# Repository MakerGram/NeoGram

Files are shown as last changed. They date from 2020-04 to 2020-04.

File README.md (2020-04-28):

# NeoGram v0.0.1α 🎨
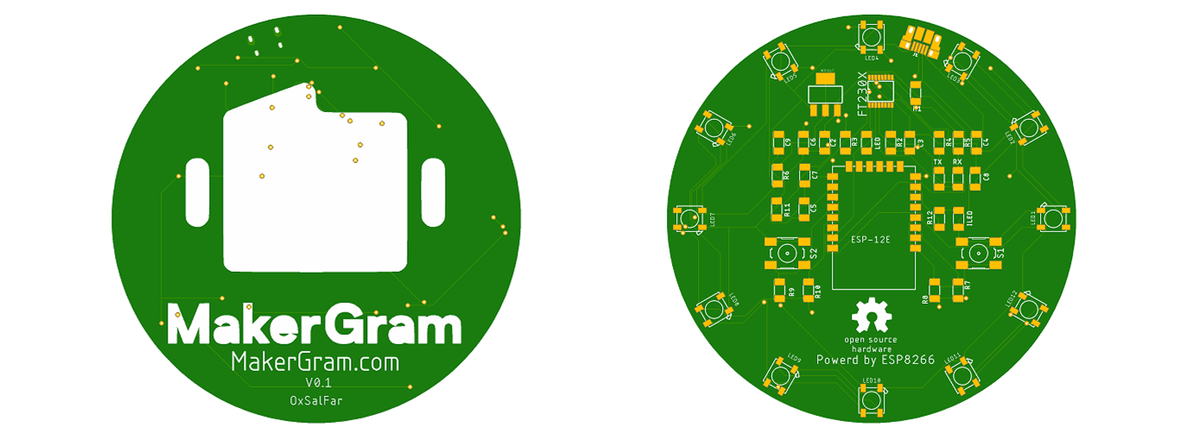
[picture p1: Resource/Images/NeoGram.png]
NeoGram


NeoGram is an ESP8266 based Open Source Hardware  Development board aimed to provide experiments on NeoPixels (WS2812B) using ESP8266. 

NeoGram is Powerd by [ESP8266-12E Module](Documents/ESP12E-Datasheet.pdf) which is encapsulates <b>Tensilica L106</b> integrates industry-leading ultra low power 32-bit MCU micro, with the 16-bit short mode,
Clock speed support 80 MHz, 160 MHz, supports the RTOS, integrated Wi-Fi MAC/BB/RF/PA/LNA, on-board antenna. The 12 of the  <b>WS2812B</b> can be progarmme indvidualy as maker wish to make there project colorfull 🌈.  

###  Features 

* 12 x Programmble WS2812B
* Plug and Play
* Inbuilt WiFi
* Inbuilt USB to UART
* Inbuild Voltage Regulator
* Reset button
* Power led
* MicroUSB port for programming and debugging 
* USB port can act like serial port, keyboard, mouse, joystick or MIDI!
* Powerd by ESP8266-12E - 32 bit, running 3.3v at 160 MHz
* Arduino Comptable 
* Micropython Compatble
* OpenSource Hardware ❤️

<br>

<hr>

## Schematic 

<p align="center">
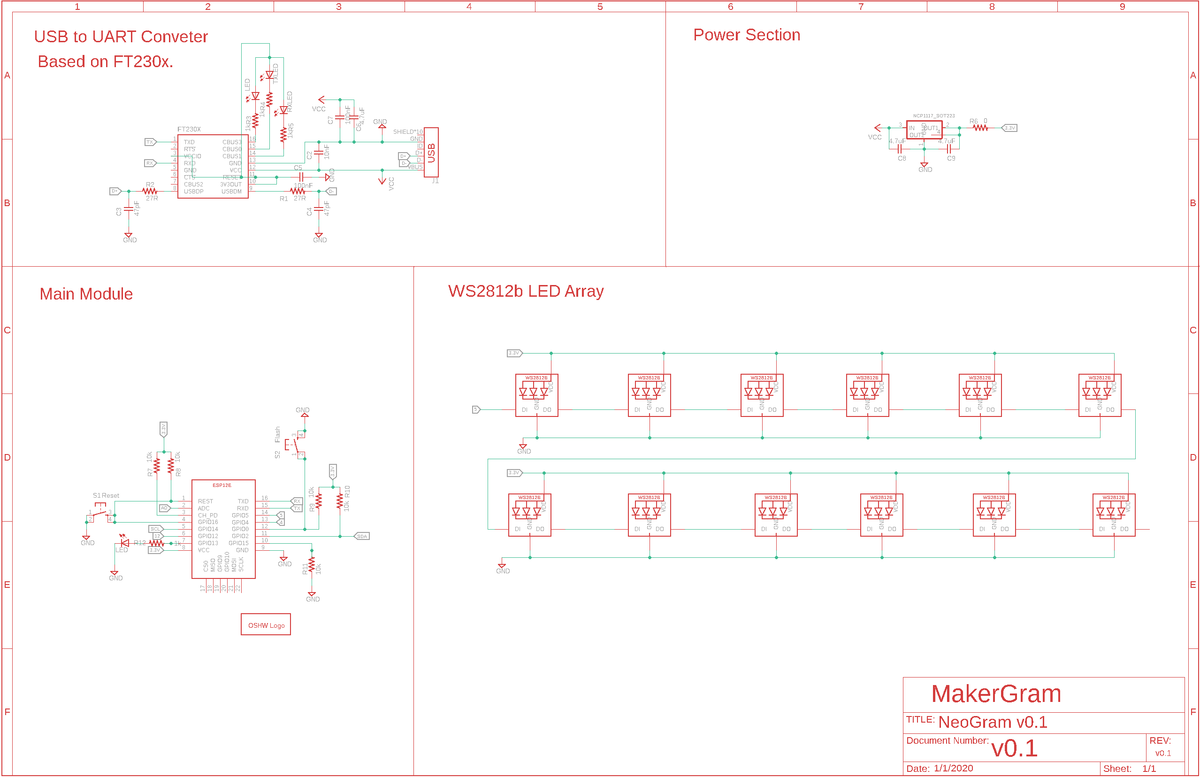
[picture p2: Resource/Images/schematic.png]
  
</p>

The [NeoGram Schematic](Hardware) Divided into Four Sections.

* ESP8266 Main Module
* WS2812B LED Array
* USB to UART
* Power Section

<hr>

## ESP8266

<p align="center">
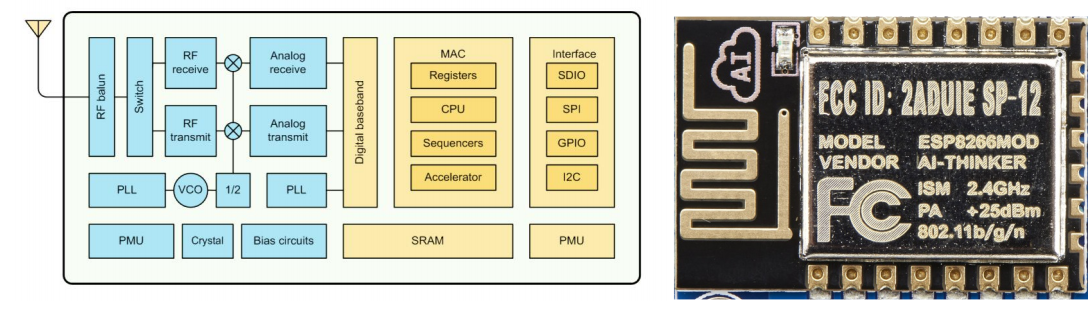
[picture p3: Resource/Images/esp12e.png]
  
</p>

The ESP8266 processor from Espressif is an 80 MHz microcontroller with a full WiFi front-end (both as client and access point) and TCP/IP stack with DNS support as well. While this chip has been very popular, its also been very difficult to use. Most of the low cost modules are not breadboard friendly, don't have an onboard 1000mA 3.3V regulator or level shifting.

The NeoGram comes with a onboard 1000mA 3.3v regulator with Arduino/MicroPython Support. 🎉

The module supports standard IEEE802.11 b/g/n agreement, complete TCP/IP protocol stack. Users can use the
add modules to an existing device networking, or building a separate network controller , so It's very conpatable for Internet Of Things project. 

<hr>

## WS2812b  

<p align="center">
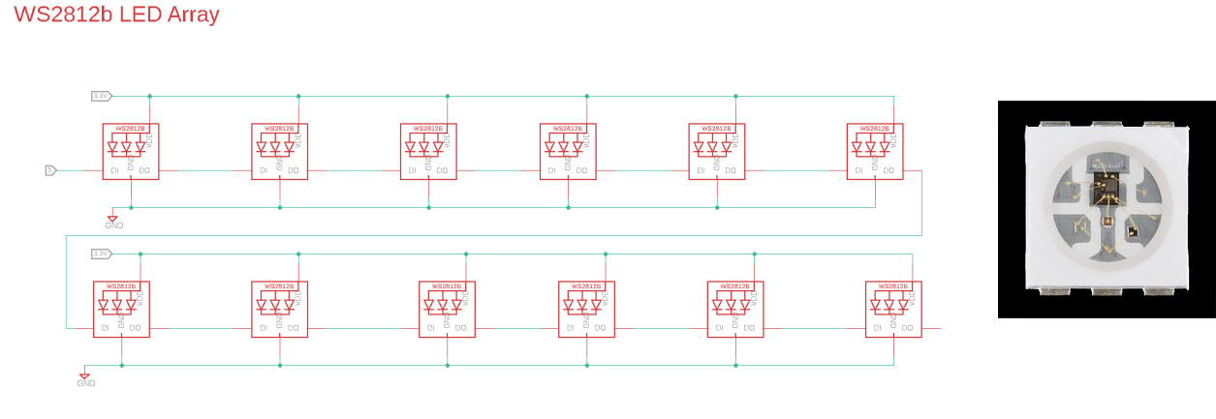
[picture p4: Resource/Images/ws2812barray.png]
  
</p>

<b>NeoGram</b> comes with 12 programable WS2812B a.k.a NeoPixel leds. NeoPixel” is Adafruit’s brand for individually-addressable RGB color pixels and strips based on the WS2812, WS2811 and SK6812 LED/drivers, using a single-wire control protocol. 

[WS2812B](Documents/WS2812B.pdf) is a intelligent control LED light source that the control circuit and RGB chip are integrated in
a package of 5050 components. It internal include intelligent digital port data latch and signal reshaping ampli
fication drive circuit. Also include a precision internal oscillator and a 12V voltage programmable constant curr
e-nt control part, effectively ensuring the pixel point light color height consisten.

<hr>

## USB to UART

<p align="center">
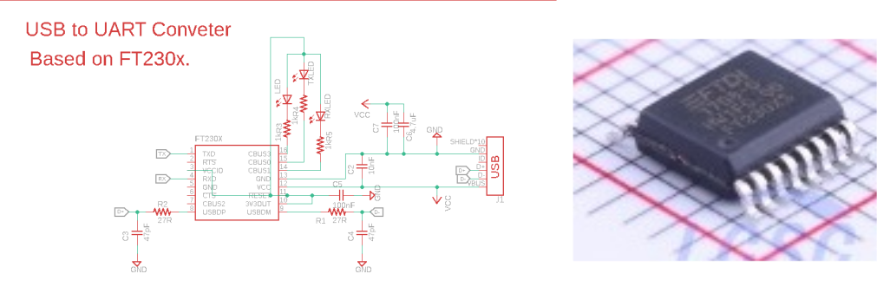
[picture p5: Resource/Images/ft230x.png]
  
</p>

NeoGram using [FT230x](Documents/ft230x.pdf). The FT230X is a USB to serial UART interface with optimised pin count for
smaller PCB designs. It act as a USB to asynchronous serial data
transfer interface and  No USB specific firmware programming required for the NeoGram. It's ahve Transmit and receive LED drive signals with dev board. 

The FTDI can act as an has an debug port so you can plug in an USB or console cable to upload software and read/write debugging information via the UART. When you're done with your coding, remove the cable, and this little module can be embeded into your project box.

<hr>

## Power

<p align="center">
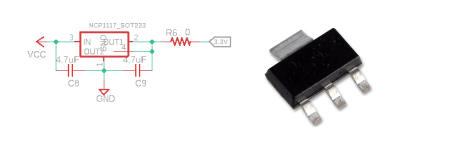
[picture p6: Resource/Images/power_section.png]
  
</p>

NeoGram comes with onboard 1000mA 3.3V regulator, so we can directly connect USB power supply without any regulator or level shifting. The Power section based on the [LM1117](Documents/lm1117.pdf), it's a The LM117 and LM317-N series of adjustable 3-pin positive voltage regulators are capable of supplying in excess of 1.5 A over a 1.25-V to 37-V output range and a wide temperature range.  we also attached 0.1uf input and output filter capacitors.

<hr><hr>

## Hero Shot

<p align="center">
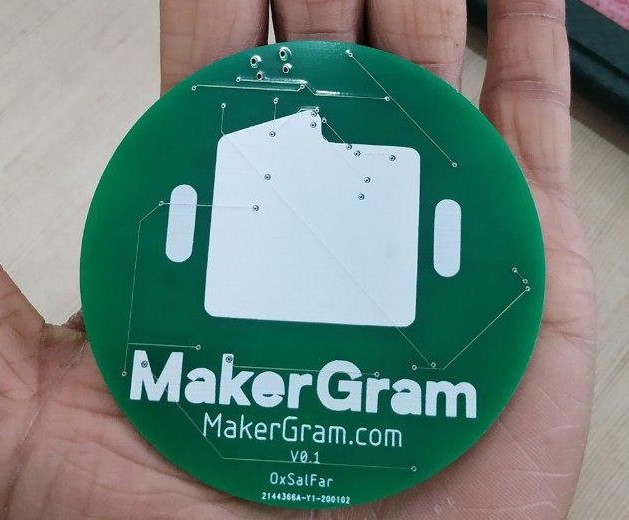
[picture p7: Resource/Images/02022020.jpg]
  
</p>

<hr>
<hr>

## Resource
* [Component Datasheets](Documents)
* [PCB Design Files](Hardware)
* [PCB Manufacturing File](Hardware/Manufacturing-File)

<hr>

## Logs

* Jan 2020: Concept and Design
* Jan 2020: Completed PCB Design
* Feb 2020: Complted PCB Fabrication 

<hr>

## To-Do

- [x] PCB Desiging.
- [x] PCB Fabrication.
- [ ] Source Components.
- [ ] Solder Components.
- [ ] Add Custom Board Definition. 

<hr>

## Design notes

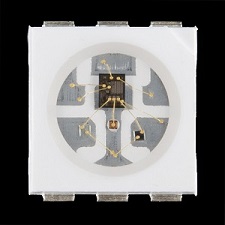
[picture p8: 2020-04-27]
Resource/Images/ws2812b.jpg

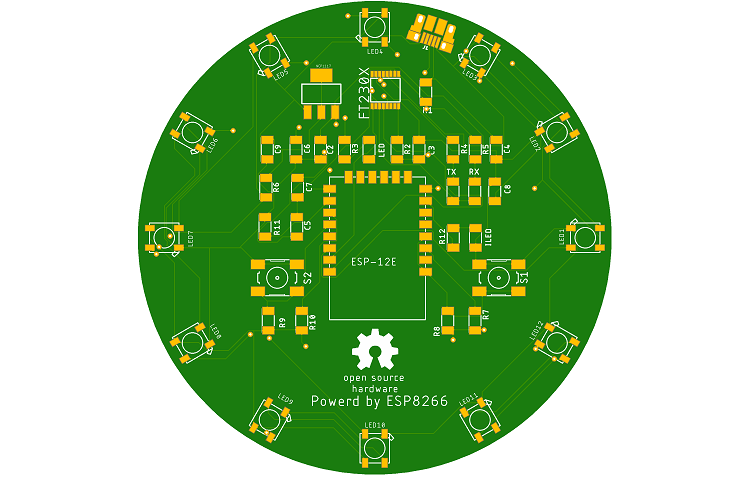
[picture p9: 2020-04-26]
Resource/Images/board_bottom.png

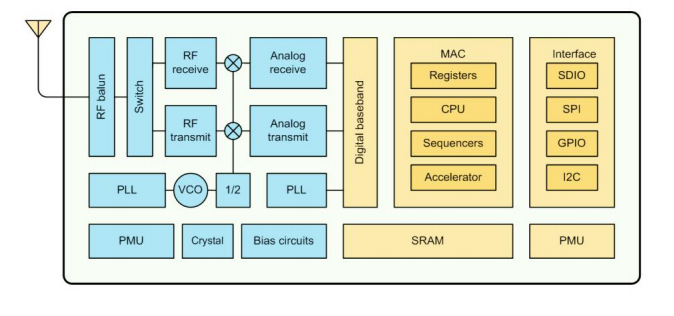
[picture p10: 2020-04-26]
Resource/Images/esp8266ex.png

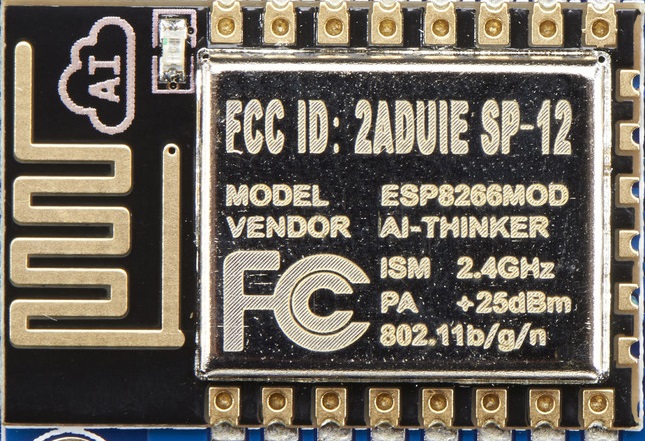
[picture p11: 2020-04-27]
Resource/Images/esp826612e.jpg

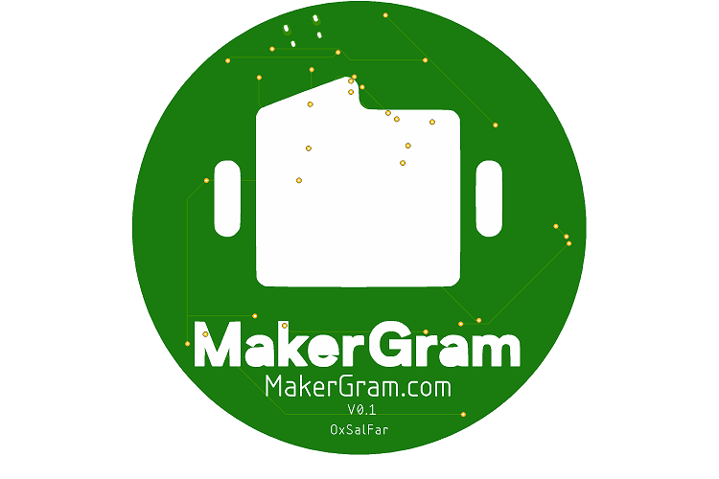
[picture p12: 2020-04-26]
Resource/Images/board_top.png

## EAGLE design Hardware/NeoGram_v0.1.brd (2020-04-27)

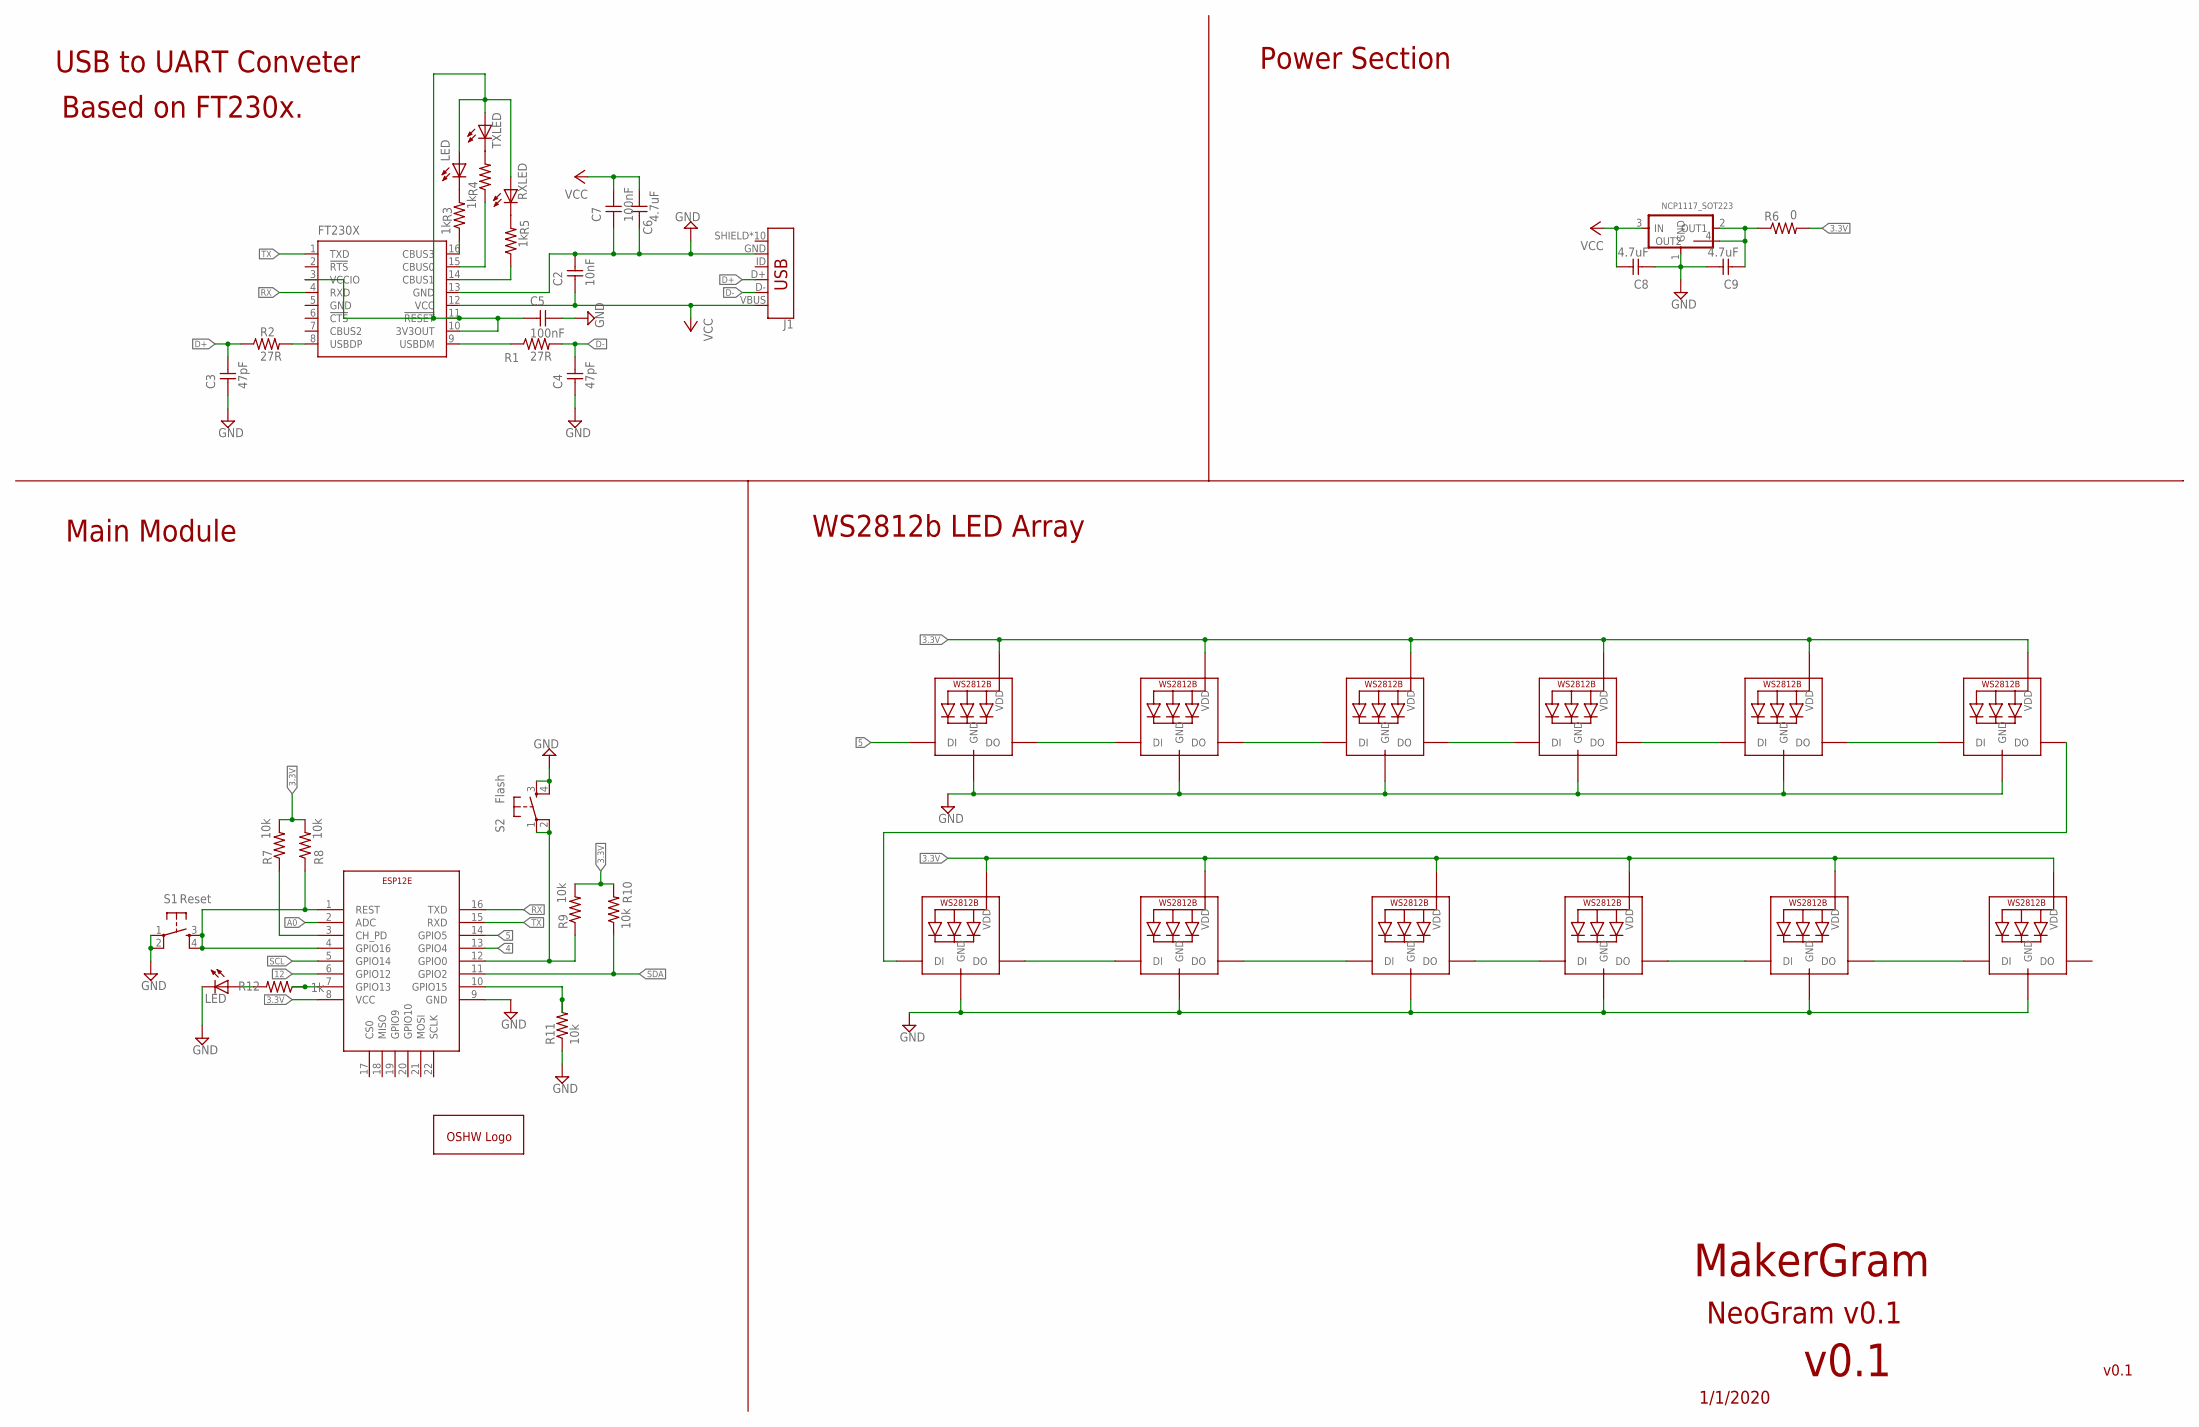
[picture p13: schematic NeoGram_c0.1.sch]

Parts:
C2: 10nF; C1206FAB
C3, C4: 47pF; C1206FAB
C5, C7: 100nF; C1206FAB
C6, C8, C9: 4.7uF; C1206FAB
FT230X: FT230XS; SSOP16
GOLD_ORB_SM1: OSHWLOGOLOGO8MM; OSHW_8MM
ILED: LED; LED1206
J1: USB_MICRO-B_HALF_PTH_MILL; USB-MICROB-PTH-MILL
LED: LED; LED1206
LED1, LED2, LED3, LED4, LED5, LED6, LED7, LED8, LED9, LED10, LED11, LED12: WS2812B5050; WS2812B
NCP1117: NCP1117_SOT223; SOT223
R1, R2: 27R; R1206
R3, R4, R5, R12: 1k; R1206
R6: 0; R1206
R7, R8, R9, R10, R11: 10k; R1206
RX: RXLED; LED1206
S1: Reset; 6MM_SWITCH
S2: Flash; 6MM_SWITCH
SJR1: ESP-12EESP12E; ESP-12E-SOC
TX: TXLED; LED1206

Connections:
3.3V: LED1.1-VDD (VDD), LED2.1-VDD (VDD), LED3.1-VDD (VDD), LED4.1-VDD (VDD), LED5.1-VDD (VDD), LED6.1-VDD (VDD), LED7.1-VDD (VDD), LED8.1-VDD (VDD), LED9.1-VDD (VDD), LED10.1-VDD (VDD), LED11.1-VDD (VDD), LED12.1-VDD (VDD), R6.2, R7.2, R8.2, R9.2, R10.2, SJR1.8 (VCC)
4: SJR1.13 (GPIO4)
5: LED1.4-DIN (DI), SJR1.14 (GPIO5)
12: SJR1.6 (GPIO12)
A0: SJR1.2 (ADC)
D+: C3.2, J1.D+, R2.1
D-: C4.2, J1.D-, R1.2
GND: C2.2, C3.1, C4.1, C5.2, C6.1, C7.1, C8.1, C9.2, FT230X.5 (GND), FT230X.13 (GND), ILED.2 (C), J1.GND, LED1.3-GND (GND), LED2.3-GND (GND), LED3.3-GND (GND), LED4.3-GND (GND), LED5.3-GND (GND), LED6.3-GND (GND), LED7.3-GND (GND), LED8.3-GND (GND), LED9.3-GND (GND), LED10.3-GND (GND), LED11.3-GND (GND), LED12.3-GND (GND), NCP1117.1 (GND), R11.1, S1.1, S1.2 (P1), S2.3 (S), S2.4 (S1), SJR1.9 (GND)
unnamed: FT230X.9 (USBDM), R1.1
unnamed: FT230X.8 (USBDP), R2.2
unnamed: R8.1, S1.3 (S), S1.4 (S1), SJR1.1 (REST), SJR1.4 (GPIO16)
unnamed: C5.1, FT230X.3 (VCCIO), FT230X.10 (3V3OUT), FT230X.11 (!RESET), LED.1 (A), RX.1 (A), TX.1 (A)
unnamed: R7.1, SJR1.3 (CH_PD)
unnamed: FT230X.16 (CBUS3), R3.1
unnamed: FT230X.15 (CBUS0), R4.1
unnamed: FT230X.14 (CBUS1), R5.1
unnamed: R5.2, RX.2 (C)
unnamed: R4.2, TX.2 (C)
unnamed: C9.1, NCP1117.2 (OUT1), NCP1117.4 (OUT2), R6.1
unnamed: R9.1, S2.1, S2.2 (P1), SJR1.12 (GPIO0)
unnamed: LED.2 (C), R3.2
unnamed: R11.2, SJR1.10 (GPIO15)
unnamed: LED1.2-DOUT (DO), LED2.4-DIN (DI)
unnamed: R12.1, SJR1.7 (GPIO13)
unnamed: ILED.1 (A), R12.2
unnamed: LED2.2-DOUT (DO), LED4.4-DIN (DI)
unnamed: LED4.2-DOUT (DO), LED6.4-DIN (DI)
unnamed: LED6.2-DOUT (DO), LED8.4-DIN (DI)
unnamed: LED3.4-DIN (DI), LED8.2-DOUT (DO)
unnamed: LED5.2-DOUT (DO), LED7.4-DIN (DI)
unnamed: LED7.2-DOUT (DO), LED10.4-DIN (DI)
unnamed: LED9.4-DIN (DI), LED10.2-DOUT (DO)
unnamed: LED9.2-DOUT (DO), LED12.4-DIN (DI)
unnamed: LED11.4-DIN (DI), LED12.2-DOUT (DO)
unnamed: LED3.2-DOUT (DO), LED5.4-DIN (DI)
RX: FT230X.4 (RXD), SJR1.16 (TXD)
SCL: SJR1.5 (GPIO14)
SDA: R10.1, SJR1.11 (GPIO2)
TX: FT230X.1 (TXD), SJR1.15 (RXD)
VCC: C2.1, C6.2, C7.2, C8.2, FT230X.12 (VCC), J1.VBUS, NCP1117.3 (IN)

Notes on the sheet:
MakerGram
NeoGram v0.1
1/1/2020
v0.1
USB to UART Conveter
Based on FT230x.
Power Section
Main Module
WS2812b LED Array

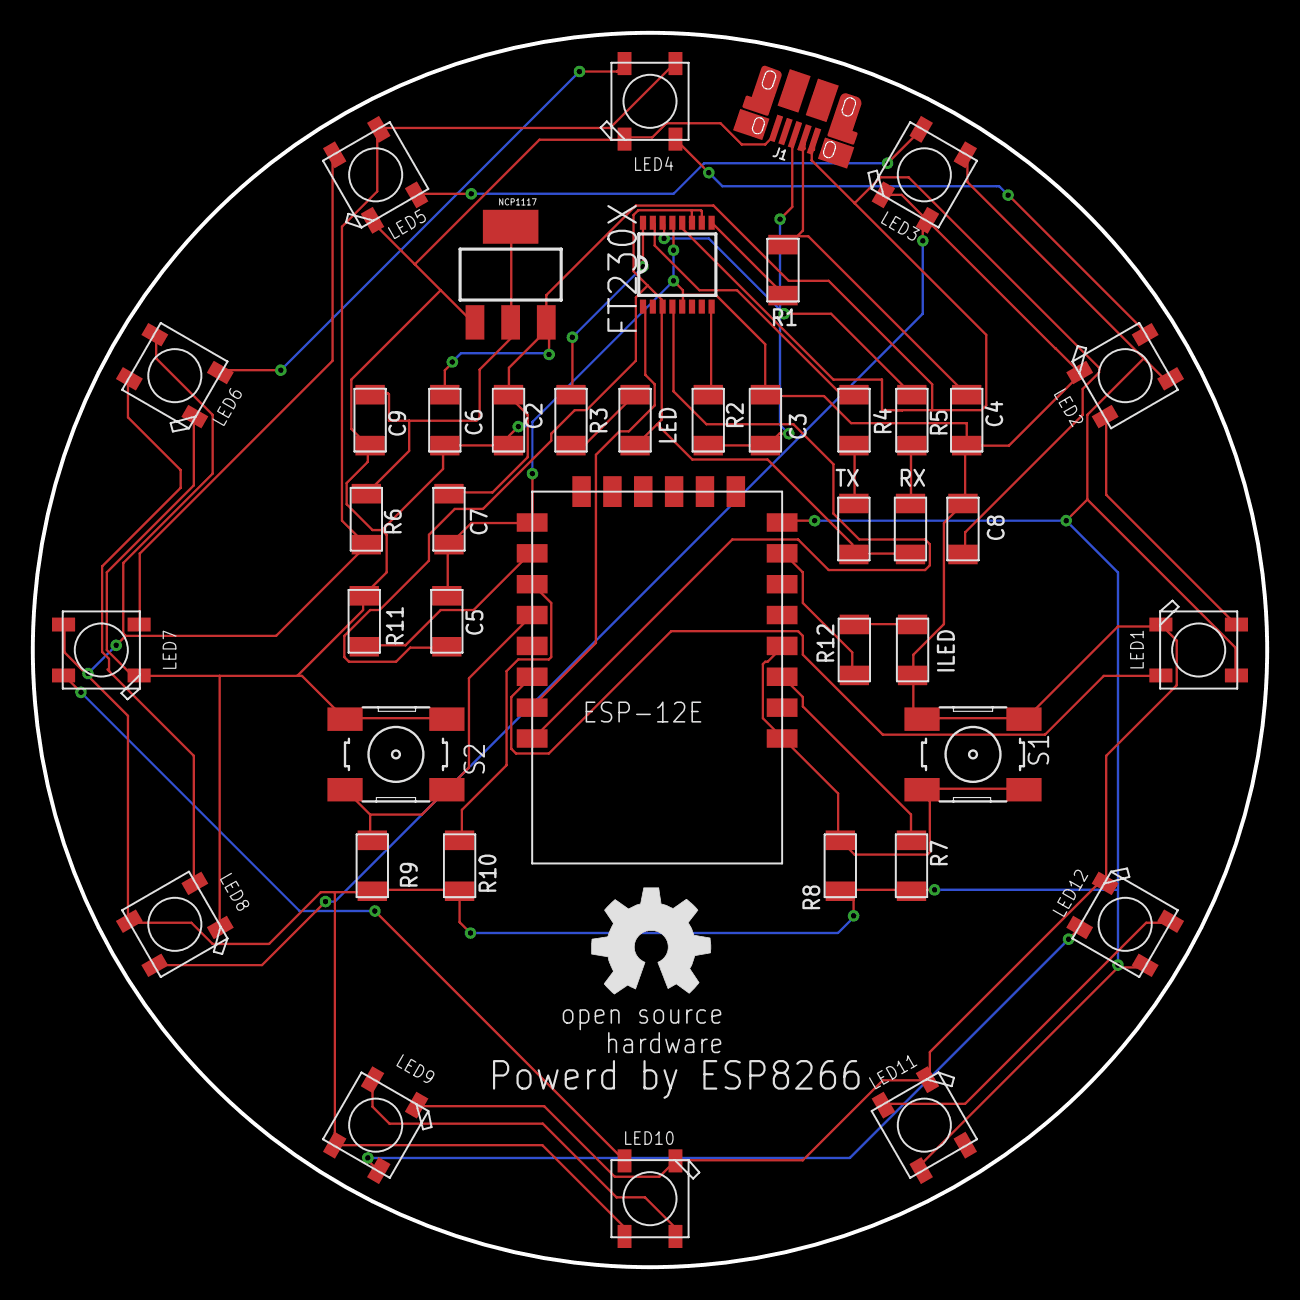
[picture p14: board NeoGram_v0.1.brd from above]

Board: 2 copper layers, 80.0 x 80.0 mm, 44 parts (0 on the bottom side), 36 nets.

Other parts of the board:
U$1: MGLOGO

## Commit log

2020-04-27 add sch img
    [NeoGram c0.1.sch, NeoGram v0.1.brd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]
2020-04-27 add esp8266 d0c
    [NeoGram c0.1.sch]
2020-04-27 added neo pixel led
2020-04-27 add led array
2020-04-27 add ToDO
    [NeoGram_c0.1.sch, NeoGram_v0.1.brd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]

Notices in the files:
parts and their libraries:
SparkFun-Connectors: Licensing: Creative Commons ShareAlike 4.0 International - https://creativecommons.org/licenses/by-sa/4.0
